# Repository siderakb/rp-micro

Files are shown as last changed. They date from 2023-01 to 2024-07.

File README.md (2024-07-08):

# RP Micro



*RP Micro* is a Pro Micro compatible RP2040 board with USB Type-C and 8MB flash, inspired by the [plut0nium/0xB2](https://github.com/plut0nium/0xB2), [joshajohnson/sea-picro](https://github.com/joshajohnson/sea-picro) and [Elite-Pi](https://docs.keeb.io/elite-pi-guide), specialized design for keyboards.

Go to [Releases](https://github.com/siderakb/rp-micro/releases) for Gerber, schematic and PCBA files.

> A part of [ErgoSNM keyboard](https://github.com/siderakb/ergo-snm-keyboard) project.

## Pinout

pinout

- [SparkFun Pro Micro - RP2040](https://www.sparkfun.com/products/18288) compatible pinout, with additional 5+2 pins (Elite-C and Elite-Pi style, but the pinout not identical to Elite-Pi).
- RAW: LDO regulator VIN pin.
- Blue LED `LD1`: State/User LED (Connect to GP25).
- All the GPIO pins of RP2040 can be used as PWM output.
- Select whether the 3rd and 4th pads in the left column are GND or GP10/GP11 by using solder bridge jumper `SB1` and `SB2`, the default is GND. To access GP10 or GP11, you need to cut the track between the solder bridge and GND pad, and then connect to the GPIO pads with solder. Great idea from Elite-Pi.

The RP2040 GPIO pin functions is very flexible, the above pinout figure is a simplified version, please refer to the [RP2040 datasheet](https://datasheets.raspberrypi.com/rp2040/rp2040-datasheet.pdf) "*1.4.3. GPIO Functions*" section for details.

## BOM
| Designator | Value | Footprint | Description |
| --- | --- | --- | --- |
| R1,R2 | 27 | 0402 (1005 Metric) | RP2040 USB D+/- series termination resistors |
| R3,R4,R9 | 1k | 0402 (1005 Metric) | |
| R5,R8 | 10k | 0402 (1005 Metric) | |
| R6,R7 | 5.1k | 0402 (1005 Metric) | USB Type-C CC resistors |
| C1,C2,C5,C6,C8,C9,C10,C11,C12,C15 | 100nF | 0402 (1005 Metric) | Flash and RP2040 decoupling capacitors |
| C3,C4 | 20pF | 0402 (1005 Metric) | Crystal load capacitors |
| C7,C13,C14,C16 | 1uF | 0402 (1005 Metric) | LDO input/output and RP2040 decoupling capacitors |
| LD1 | BLUE | 0603 (1608 Metric) | State/User LED |
| D1 | B5817 | SOD-323 | USB VBUS diode |
| F1 | 500mA, 6V | 0805 (2012 Metric) | USB VBUS fuse |
| J1 | USB-C Mid-Mount Receptacle 16P | 918-418K2024S40000 | USB Type-C connector |
| SW1,SW2 | BOOT and RESET buttons | B3U-1000P | Buttons |
| U1 | RP2040 | QFN-56-1EP 7x7mm P0.4mm EP3.2x3.2mm | MCU |
| U2 | W25Q64JVXGIQ | XSON-8 (4x4mm) | 8MB (64Mbit) flash |
| U3 | RT9013-33GB | SOT-23-5 | 3.3V/500mA LDO regulator |
| Y1 | 12MHz | 3225-4Pin (3.2x2.5mm) | Crystal for RP2040 |

There is not designator silkscreen on PCB, please use your browser to open the `ibom.html` file (placed in [Release page](https://github.com/siderakb/rp-micro/releases) and [`bom/ibom.html`](./bom/ibom.html)) to refer to the placement of the parts, it is generated by [Interactive HTML BOM](https://github.com/openscopeproject/InteractiveHtmlBom) plugin. 

> See also [`PCBA/rp-micro_bom.csv`](./PCBA/rp-micro_bom.csv)

## PCB

| Top | Bottom | Layers |
| :---: | :---: | :---: |
| top | bottom | layers |

## PCBA

Support JLCPCB's PCBA service, the BOM and CPL files for PCBA are placed in the [`PCBA`](./PCBA/) folder and [Releases](https://github.com/ziteh/rp-micro/releases) page, files are generated by [KiCad JLCPCB Tools](https://github.com/Bouni/kicad-jlcpcb-tools) plugin.

## Board Characteristics

- Copper layer count: 2
- Board thickness: 1.6 mm
- Board overall dimensions: 17.78 x 33.02 mm (0.7 x 1.3 inch)
- Min track/spacing: 0.127 mm / 0.127 mm
- Min hole diameter: 0.3 mm
- Castellated pads: No
- Edge card connectors: No
- Plated board edge: No

## Disclaimer

These files are provided **AS IS**, without warranty of any kind, express or implied.  
Including but not limited to manufacturing, assembly, procurement and use at your own risk.  
It is recommended to check yourself before use.

For the full statement, please see [LICENSE](./LICENSE).

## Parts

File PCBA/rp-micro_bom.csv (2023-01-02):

Comment | Designator | Footprint | LCSC
1k | R3,R4,R9 | R_0402_1005Metric | C11702
B5817 | D1 | D_SOD-323_HandSoldering | C123899
20pF | C3,C4 | C_0402_1005Metric | C1554
USB_C_Receptacle_USB2.0 | J1 | USB Type-C Mid-Mount Receptacle 16P | C168688
RP2040 | U1 | QFN-56-1EP_7x7mm_P0.4mm_EP3.2x3.2mm | C2040
BOOT | SW1,SW2 | SW_SPST_B3U-1000P | C231329
27 | R1,R2 | R_0402_1005Metric | C25100
10k | R5,R8 | R_0402_1005Metric | C25744
5.1k | R6,R7 | R_0402_1005Metric | C25905
500mA, 6V | F1 | Fuse_0805_2012Metric | C269104
W25Q64JVXGIQ | U2 | XSON-8 (4x4mm) | C2940195
100nF | C1,C10,C11,C12,C15,C2,C5,C6,C8,C9 | C_0402_1005Metric | C307331
RT9013-33GB | U3 | SOT-23-5 | C47773
1uF | C13,C14,C16,C7 | C_0402_1005Metric | C52923
BLUE | LD1 | LED_0603_1608Metric | C72041
12MHz | Y1 | Crystal_SMD_3225-4Pin_3.2x2.5mm | C9002

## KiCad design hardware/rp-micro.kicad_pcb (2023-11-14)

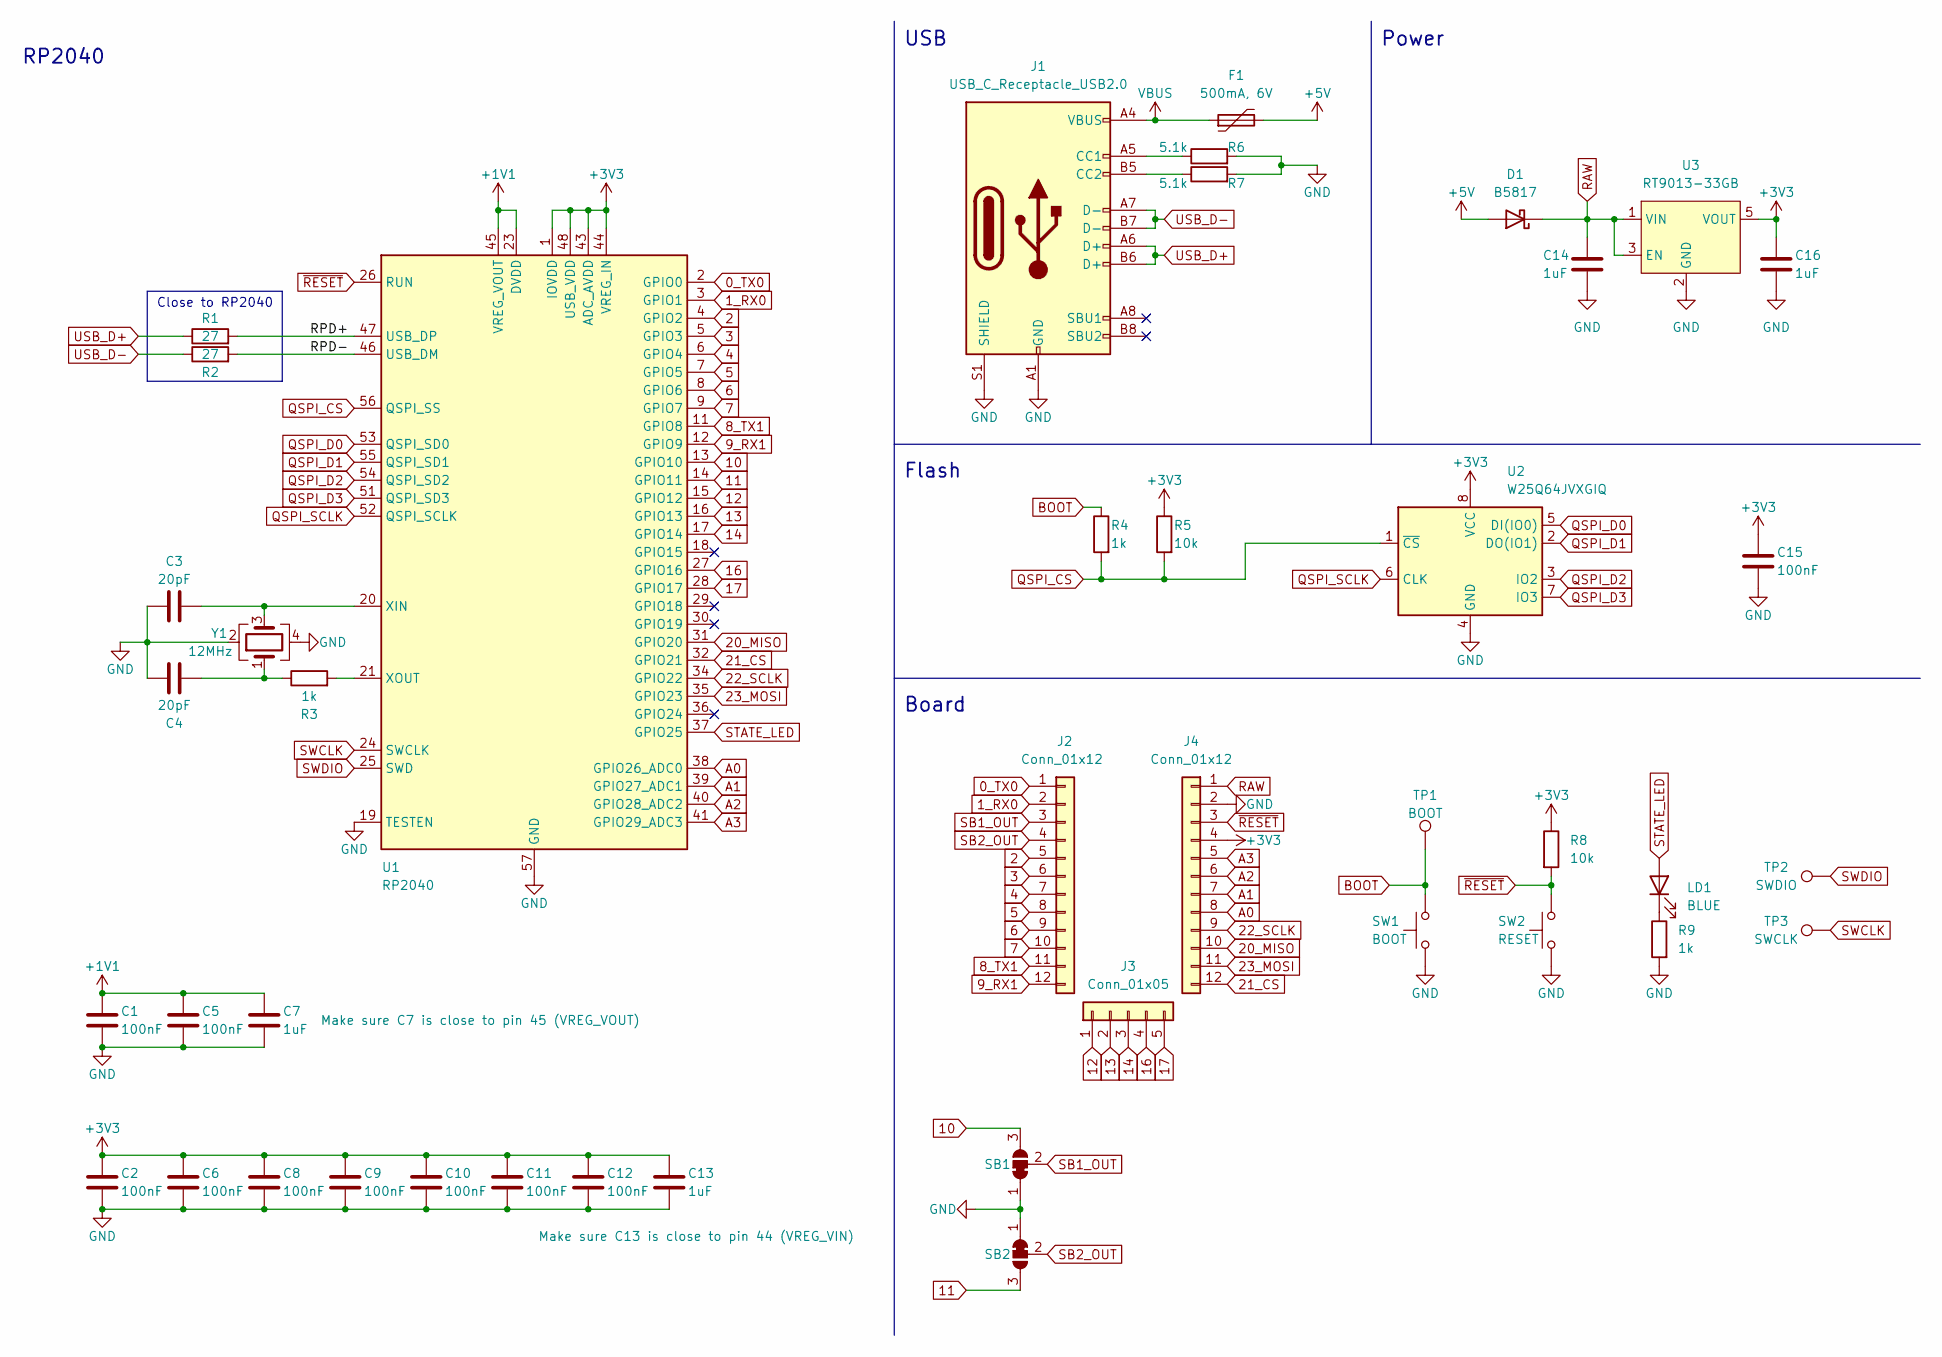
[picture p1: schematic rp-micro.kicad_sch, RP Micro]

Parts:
C1, C2, C5, C6, C8, C9, C10, C11, C12, C15: 100nF; C_0402_1005Metric; MFR. Part # CL05B104KB54PNC; JLCPCB Part # C307331
C3, C4: 20pF; C_0402_1005Metric; MFR. Part # 0402CG200J500NT; JLCPCB Part # C1554
C7, C13, C14, C16: 1uF; C_0402_1005Metric; MFR. Part # CL05A105KA5NQNC; JLCPCB Part # C52923
D1: B5817; D_SOD-323_HandSoldering; MFR. Part # B5817WS; JLCPCB Part # C123899
F1: 500mA, 6V; Fuse_0805_2012Metric; MFR. Part # SMD0805B050TF; JLCPCB Part # C269104
J1: USB_C_Receptacle_USB2.0; USB Type-C Mid-Mount Receptacle 16P; MFR. Part # 918-418K2024S40000; JLCPCB Part # C168688
J2, J4: Conn_01x12; PinHeader_1x12_P2.54mm_Vertical
J3: Conn_01x05; PinHeader_1x05_P2.54mm_Vertical
LD1: BLUE; LED_0603_1608Metric; MFR. Part # 19-217/BHC-ZL1M2RY/3T; JLCPCB Part # C72041
R1, R2: 27; R_0402_1005Metric; MFR. Part # 0402WGF270JTCE; JLCPCB Part # C25100
R3, R4, R9: 1k; R_0402_1005Metric; MFR. Part # 0402WGF1001TCE; JLCPCB Part # C11702
R5, R8: 10k; R_0402_1005Metric; MFR. Part # 0402WGF1002TCE; JLCPCB Part # C25744
R6, R7: 5.1k; R_0402_1005Metric; MFR. Part # 0402WGF5101TCE; JLCPCB Part # C25905
SB1, SB2: SolderJumper_3_Bridged12; SolderJumper-3_P1.3mm_Bridged12_Pad1.0x1.5mm
SW1: BOOT; SW_SPST_B3U-1000P; MFR. Part # B3U-1000P; JLCPCB Part # C231329
SW2: RESET; SW_SPST_B3U-1000P; MFR. Part # B3U-1000P; JLCPCB Part # C231329
TP1: BOOT; TestPoint_Pad_D2.0mm
TP2: SWDIO; TestPoint_Pad_D2.0mm
TP3: SWCLK; TestPoint_Pad_D2.0mm
U1: RP2040; QFN-56-1EP_7x7mm_P0.4mm_EP3.2x3.2mm; MFR. Part # RP2040; JLCPCB Part # C2040
U2: W25Q64JVXGIQ; XSON-8 (4x4mm); MFR. Part # W25Q64JVXGIQ; JLCPCB Part # C2940195
U3: RT9013-33GB; SOT-23-5; MFR. Part # RT9013-33GB; JLCPCB Part # C47773
Y1: 12MHz; Crystal_SMD_3225-4Pin_3.2x2.5mm; MFR. Part # X322512MSB4SI; JLCPCB Part # C9002

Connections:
0_TX0: J2.1, U1.2 (GPIO0)
1_RX0: J2.2, U1.3 (GPIO1)
2: J2.5, U1.4 (GPIO2)
3: J2.6, U1.5 (GPIO3)
4: J2.7, U1.6 (GPIO4)
5: J2.8, U1.7 (GPIO5)
6: J2.9, U1.8 (GPIO6)
7: J2.10, U1.9 (GPIO7)
8_TX1: J2.11, U1.11 (GPIO8)
9_RX1: J2.12, U1.12 (GPIO9)
10: SB1.3 (B), U1.13 (GPIO10)
11: SB2.3 (B), U1.14 (GPIO11)
12: J3.1, U1.15 (GPIO12)
13: J3.2, U1.16 (GPIO13)
14: J3.3, U1.17 (GPIO14)
16: J3.4, U1.27 (GPIO16)
17: J3.5, U1.28 (GPIO17)
20_MISO: J4.10, U1.31 (GPIO20)
21_CS: J4.12, U1.32 (GPIO21)
22_SCLK: J4.9, U1.34 (GPIO22)
23_MOSI: J4.11, U1.35 (GPIO23)
+1V1: C1.1, C5.1, C7.1, U1.23 (DVDD), U1.45 (VREG_VOUT), U1.50 (DVDD)
+3V3: C2.1, C6.1, C8.1, C9.1, C10.1, C11.1, C12.1, C13.1, C15.1, C16.1, J4.4, R5.1, R8.1, U1.1 (IOVDD), U1.10 (IOVDD), U1.22 (IOVDD), U1.33 (IOVDD), U1.42 (IOVDD), U1.43 (ADC_AVDD), U1.44 (VREG_IN), U1.48 (USB_VDD), U1.49 (IOVDD), U2.8 (VCC), U3.5 (VOUT)
+5V: D1.2 (A), F1.2
/RPD+: R1.2, U1.47 (USB_DP)
/RPD-: R2.2, U1.46 (USB_DM)
A0: J4.8, U1.38 (GPIO26_ADC0)
A1: J4.7, U1.39 (GPIO27_ADC1)
A2: J4.6, U1.40 (GPIO28_ADC2)
A3: J4.5, U1.41 (GPIO29_ADC3)
BOOT: R4.1, SW1.2, TP1.1
GND: C1.2, C2.2, C3.1, C4.1, C5.2, C6.2, C7.2, C8.2, C9.2, C10.2, C11.2, C12.2, C13.2, C14.2, C15.2, C16.2, J1.A1 (GND), J1.A12 (GND), J1.B1 (GND), J1.B12 (GND), J1.S1 (SHIELD), J4.2, R6.2, R7.2, R9.2, SB1.1 (A), SB2.1 (A), SW1.1, SW2.1, U1.19 (TESTEN), U1.57 (GND), U2.4 (GND), U3.2 (GND), Y1.2, Y1.4
unnamed: C3.2, U1.20 (XIN), Y1.3
unnamed: C4.2, R3.1, Y1.1
unnamed: J1.A5 (CC1), R6.1
unnamed: J1.B5 (CC2), R7.1
unnamed: LD1.1 (K), R9.1
unnamed: R3.2, U1.21 (XOUT)
QSPI_CS: R4.2, R5.2, U1.56 (QSPI_SS), U2.1 (~CS)
QSPI_D0: U1.53 (QSPI_SD0), U2.5 (DI(IO0))
QSPI_D1: U1.55 (QSPI_SD1), U2.2 (DO(IO1))
QSPI_D2: U1.54 (QSPI_SD2), U2.3 (IO2)
QSPI_D3: U1.51 (QSPI_SD3), U2.7 (IO3)
QSPI_SCLK: U1.52 (QSPI_SCLK), U2.6 (CLK)
RAW: C14.1, D1.1 (K), J4.1, U3.1 (VIN), U3.3 (EN)
SB1_OUT: J2.3, SB1.2 (C)
SB2_OUT: J2.4, SB2.2 (C)
STATE_LED: LD1.2 (A), U1.37 (GPIO25)
SWCLK: TP3.1, U1.24 (SWCLK)
SWDIO: TP2.1, U1.25 (SWD)
USB_D+: J1.A6 (D+), J1.B6 (D+), R1.1
USB_D-: J1.A7 (D-), J1.B7 (D-), R2.1
VBUS: F1.1, J1.A4 (VBUS), J1.A9 (VBUS), J1.B4 (VBUS), J1.B9 (VBUS)
~RESET: J4.3, R8.2, SW2.2, U1.26 (RUN)

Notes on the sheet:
Flash
Close to RP2040
Power
RP2040
USB
Board

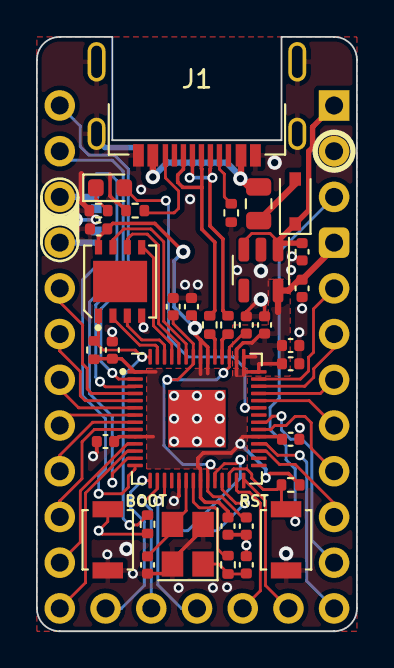
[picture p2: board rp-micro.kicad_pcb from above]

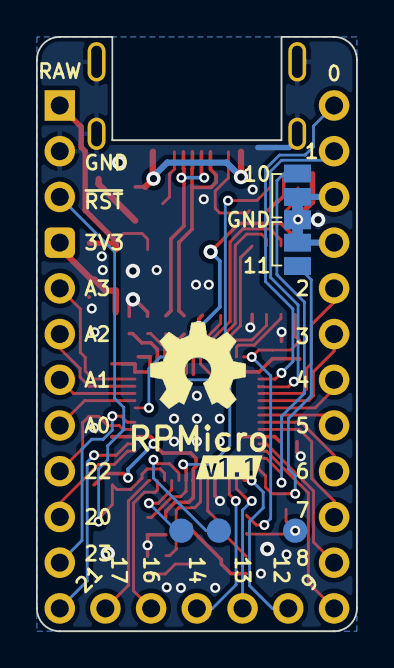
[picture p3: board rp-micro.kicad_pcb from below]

Board: 2 copper layers, 17.8 x 33.0 mm, 44 parts (8 on the bottom side), 54 nets.

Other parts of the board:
kibuzzard-637CA201: G***; kibuzzard-637CA201

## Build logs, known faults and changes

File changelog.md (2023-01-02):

# Changelog

## [1.1.0] 2023-01-02
### Added
- Solder bridges SB1 and SB2 added. This allows the user to select whether pins 3 and 4 of the left pin header are GND or GPIO10 and 11 respectively.

### Removed
- Remove 3.3V power indicator.

### Changed
- Replace USB Type-C to mid-mount receptacle, from "HRO TYPE-C-31-M-12" to "918-418K2024S40000".
- Change the bottom row pinout, from "GP10, 11, 12, 16, 17" to "GP12, 13, 14, 16, 17".
- Increase the size of SWDIO and SWCLK pads.
- Change the D1 footprint to hand soldering version.
- Replace the LED series resistor with a higher resistance value.

## [1.0.0] 2022-11-07
First release.

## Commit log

2022-10-30 Add KiCad project
    [rp-micro.kicad_pcb, rp-micro.kicad_sch]
2022-11-01 Add BOM doc
2022-11-01 Update license
    [rp-micro.kicad_pcb, rp-micro.kicad_sch]
2022-11-01 Move BOM
2022-11-01 Update track
    [rp-micro.kicad_pcb, rp-micro.kicad_sch]
2022-11-02 Update silkscreen
    [rp-micro.kicad_pcb]
2022-11-03 Add PCBA files
    [rp-micro_v1.0_bom.csv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]
2022-11-06 Rename BOM & CPL csv files
    [rp-micro_bom.csv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]
2022-11-06 Update BOM & CPL files for PCBA
    [rp-micro_bom.csv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]
2022-11-06 Update BOM
2022-11-07 Replace flash to W25Q64JVXGIQ
    [rp-micro.kicad_pcb, rp-micro.kicad_sch]
2022-11-07 Improve 3v3 route
    [rp-micro.kicad_pcb, rp-micro.kicad_sch]
2022-11-07 Update BOM and CPL files for PCBA
    [rp-micro_bom.csv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]
2022-11-07 Update note
    [rp-micro.kicad_sch]
2022-11-13 Fix the typo
    [rp-micro.kicad_sch]
2022-11-22 rev 1.1 completed
    [rp-micro.kicad_pcb, rp-micro.kicad_sch]
2022-11-23 Update PCBA files
    [rp-micro.kicad_pcb, rp-micro.kicad_sch, rp-micro_bom.csv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]
2022-12-07 Change D1 footprint to hand soldering version
    [rp-micro.kicad_pcb, rp-micro.kicad_sch]
2023-01-02 Update BOM, CPL , readme and changelog
    [rp-micro_bom.csv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]
2023-04-29 Add footprint and symbol library path table
2023-11-14 Change license from MIT to CERN-OHL-P v2
    [rp-micro.kicad_pcb, rp-micro.kicad_sch]

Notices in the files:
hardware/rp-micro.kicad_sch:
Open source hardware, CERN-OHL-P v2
